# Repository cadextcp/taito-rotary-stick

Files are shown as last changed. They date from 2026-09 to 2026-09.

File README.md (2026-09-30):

# Taito Rotary Stick – druckbarer Nachbau

Nachbau des Taito „Aim-n-Fire“-Rotary-Sticks (Front Line, Wild Western, The Tin Star):
8 Rastpositionen, 4 Richtungs-Microtaster (8-Wege-Logik wie ein Joystick) und ein Fire-Taster,
der durch Herunterdrücken des Knopfs auslöst. Aufbau nach der Explosionszeichnung
„Revolving Control Assembly (WWK00003)“, Fig. 15. Parametrisch in [build123d](https://github.com/gumyr/build123d).

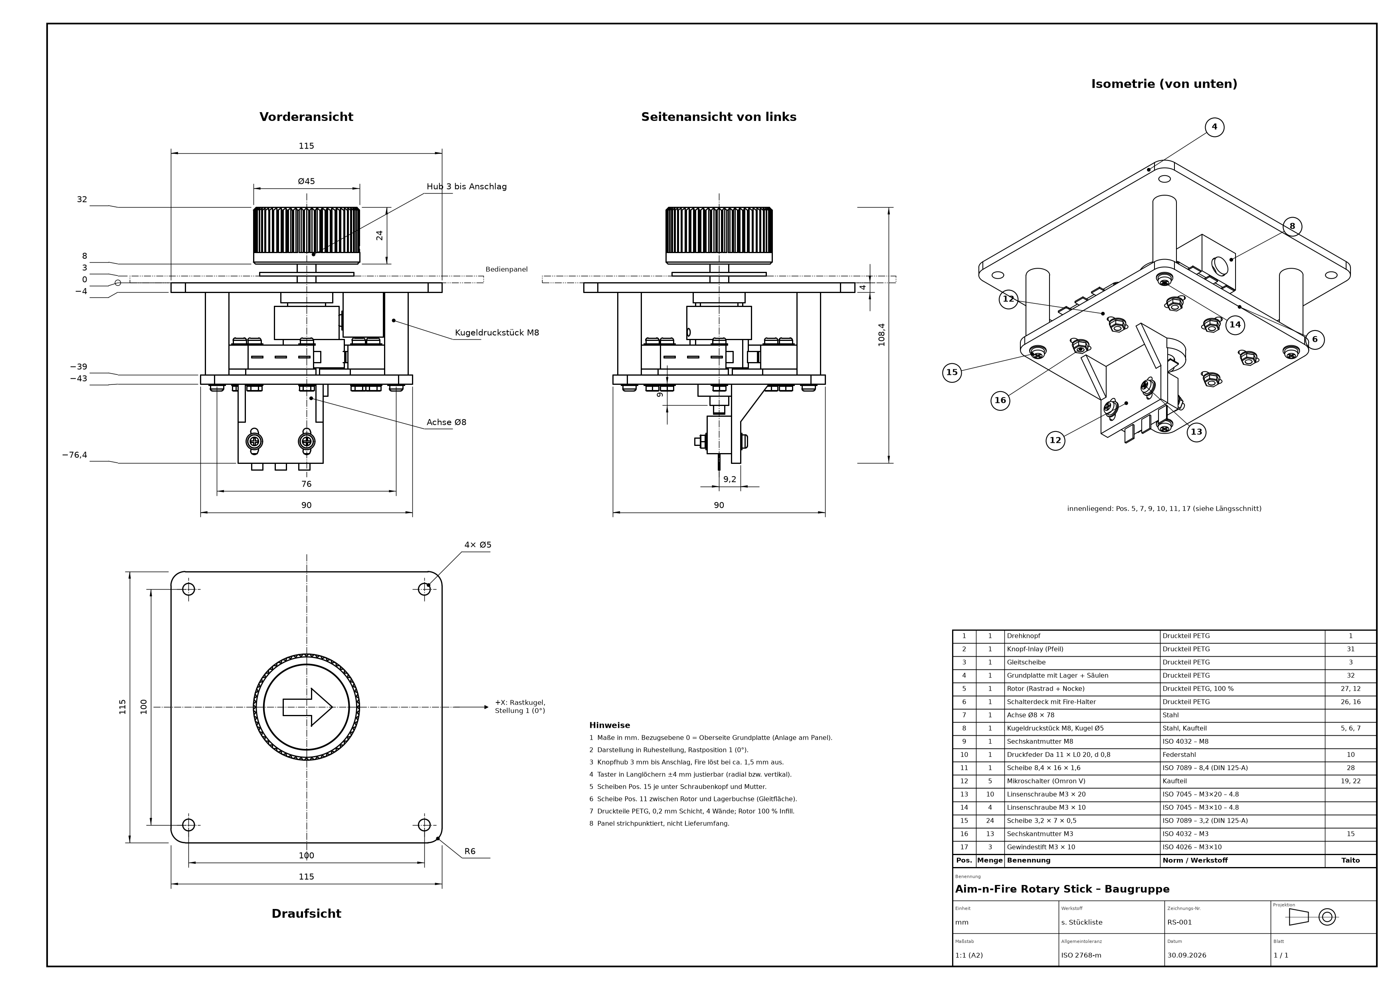
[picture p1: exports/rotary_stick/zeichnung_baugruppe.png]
Zeichnung


| Animation | Längsschnitt |
|---|---|
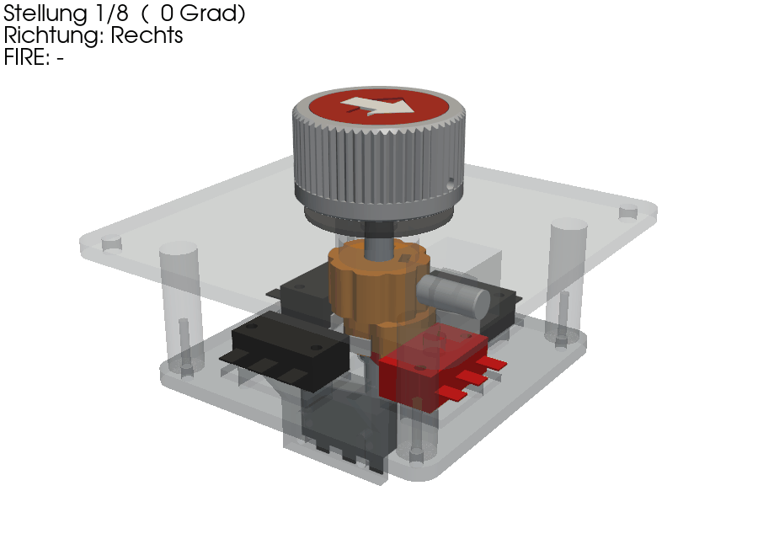
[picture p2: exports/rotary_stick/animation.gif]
Animation
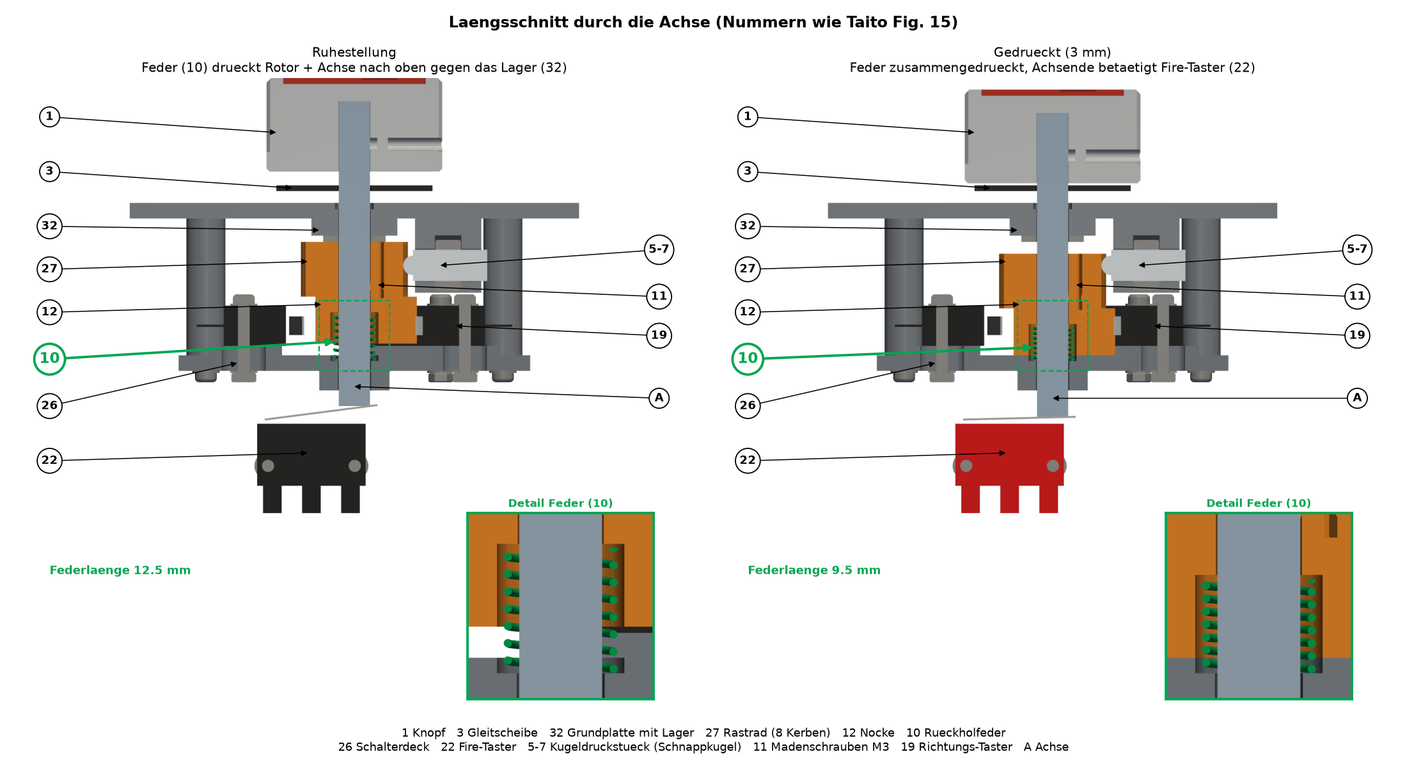
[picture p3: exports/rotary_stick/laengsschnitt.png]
Längsschnitt
|  |  |

## Inhalt

| Pfad | Inhalt |
|---|---|
| `models/rotary_stick.py` | Parametrisches Modell mit Plausibilitätsprüfungen (Schaltlogik, Kollisionen, Hub), exportiert STL/STEP |
| `scripts/drawing_rotary.py` | Bemaßte Baugruppenzeichnung A2 mit Stückliste (PDF/PNG) |
| `scripts/section_rotary.py` | Längsschnitt Ruhe/gedrückt mit Rückholfeder |
| `scripts/animate_rotary.py` | Animation Drehen/Drücken mit Tasterreaktion (GIF) |
| `scripts/render_rotary.py` | Vorschaubilder (Baugruppe, Explosion, Schaltlogik) |
| `exports/rotary_stick/` | Druckfertige STL (in Druckorientierung), STEP, Zeichnung, Bilder, [Bauanleitung](exports/rotary_stick/BAUANLEITUNG.md) |

## Funktion

- **8 Klicks:** Kugeldruckstück rastet radial in 8 senkrechte Kerben des Rastrads. Die Kerben laufen axial,
  daher stört der Fire-Hub die Rastung nicht.
- **8 Richtungen mit 4 Tastern:** Nocke mit ~96° Nockenbreite drückt in den Hauptrichtungen einen, in den
  Diagonalen zwei benachbarte Taster. Schaltfenster ≈ 3,7 mm, Taster in Langlöchern justierbar.
- **Fire:** Knopf 3 mm bis Anschlag drücken, das Achsende betätigt den unteren Taster; die Druckfeder im Rotor
  stellt zurück. Die Nocke überdeckt die Taster-Hebel über den ganzen Hub (wird im Skript geprüft).

## Neu erzeugen

```bash
python -m venv .venv
.venv/Scripts/pip install -r requirements.txt   # Linux/macOS: .venv/bin/pip
.venv/Scripts/python models/rotary_stick.py      # STL/STEP + Prüfungen
.venv/Scripts/python scripts/drawing_rotary.py   # Zeichnung
```

Maße der Kaufteile (Achse, Kugeldruckstück, Taster) stehen als Parameter oben in `models/rotary_stick.py`
und sollten vor dem Druck nachgemessen werden.

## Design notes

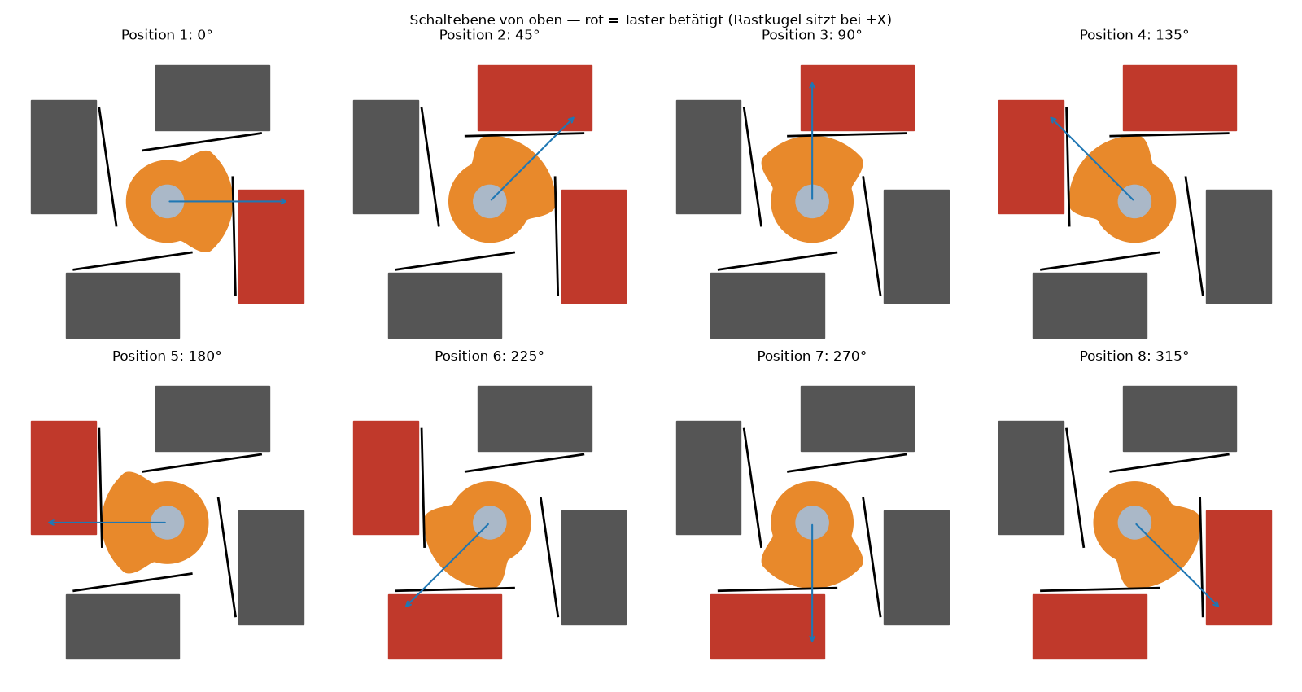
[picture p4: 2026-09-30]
exports/rotary_stick/vorschau_schaltlogik.png

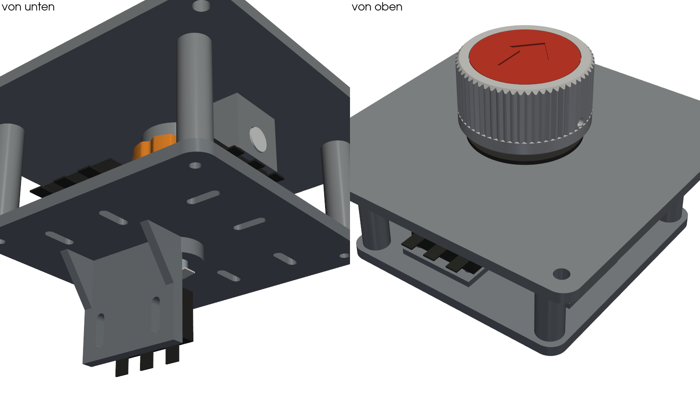
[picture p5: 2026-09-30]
exports/rotary_stick/vorschau_baugruppe.png

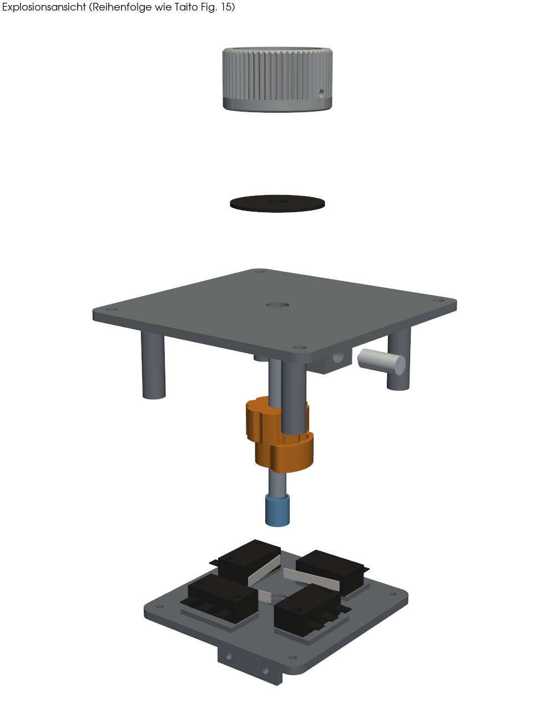
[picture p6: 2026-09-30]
exports/rotary_stick/vorschau_explosion.png

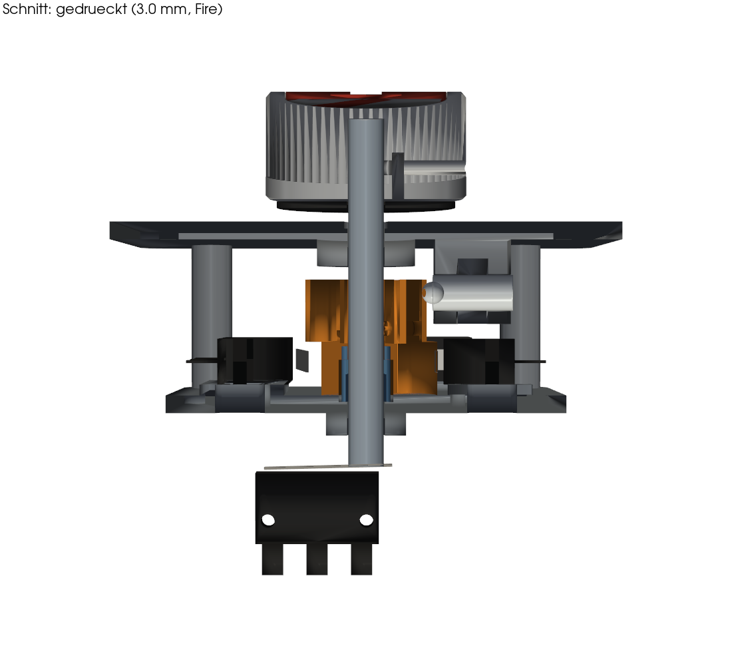
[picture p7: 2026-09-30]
exports/rotary_stick/vorschau_schnitt_gedrueckt.png

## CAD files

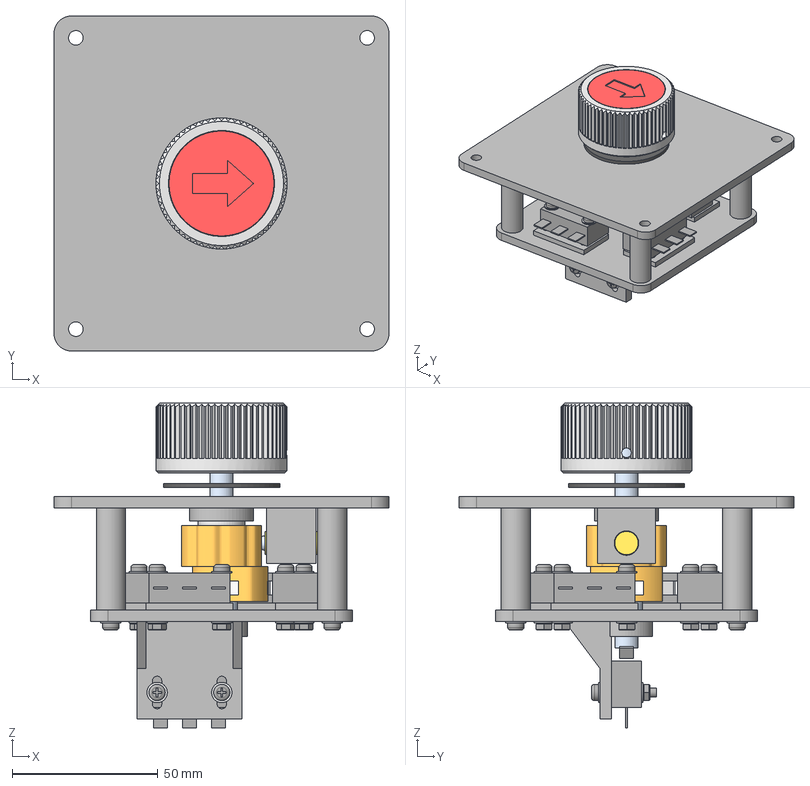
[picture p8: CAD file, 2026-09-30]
exports/rotary_stick/baugruppe.step
115.0 x 115.0 x 111.4 mm
grundplatte
rotor
schalterdeck
knopf
inlay
scheibe
achse
kugel
kugeldruckstueck
feder
taster_0
hebel_0
taster_1
hebel_1
taster_2
hebel_2
taster_3
hebel_3
taster_fire
hebel_fire
u_scheibe_28
u_scheibe_m3_o00
schraube_m3x20_00
u_scheibe_m3_u00
mutter_m3_00
u_scheibe_m3_o01
schraube_m3x20_01
u_scheibe_m3_u01
mutter_m3_01
u_scheibe_m3_o10
schraube_m3x20_10
u_scheibe_m3_u10
mutter_m3_10
u_scheibe_m3_o11
schraube_m3x20_11
u_scheibe_m3_u11
mutter_m3_11
u_scheibe_m3_o20
schraube_m3x20_20
u_scheibe_m3_u20
mutter_m3_20
u_scheibe_m3_o21
schraube_m3x20_21
u_scheibe_m3_u21
mutter_m3_21
u_scheibe_m3_o30
schraube_m3x20_30
u_scheibe_m3_u30
mutter_m3_30
u_scheibe_m3_o31
schraube_m3x20_31
u_scheibe_m3_u31
mutter_m3_31
u_scheibe_m3_d-1-1
schraube_m3x10_-1-1
u_scheibe_m3_d-11
schraube_m3x10_-11
u_scheibe_m3_d1-1
schraube_m3x10_1-1
u_scheibe_m3_d11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

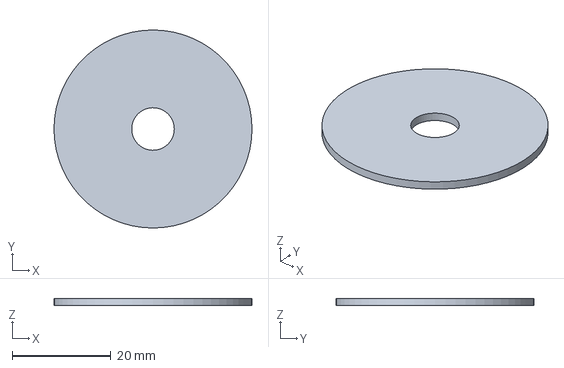
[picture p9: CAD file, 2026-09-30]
exports/rotary_stick/scheibe.step
40.0 x 40.0 x 1.50 mm

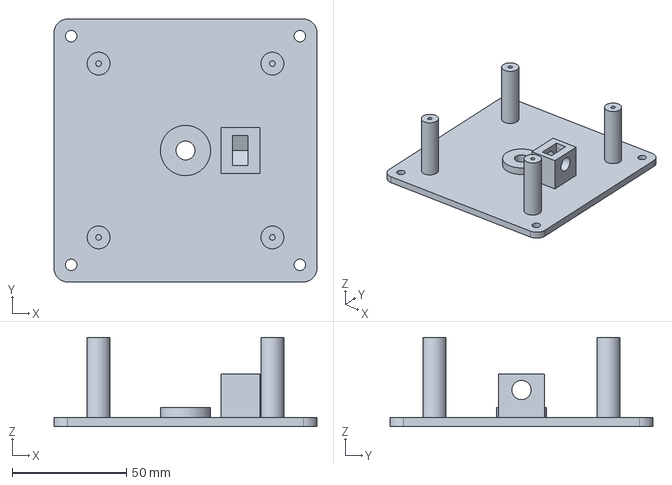
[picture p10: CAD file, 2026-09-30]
exports/rotary_stick/grundplatte.step
115.0 x 115.0 x 39.0 mm

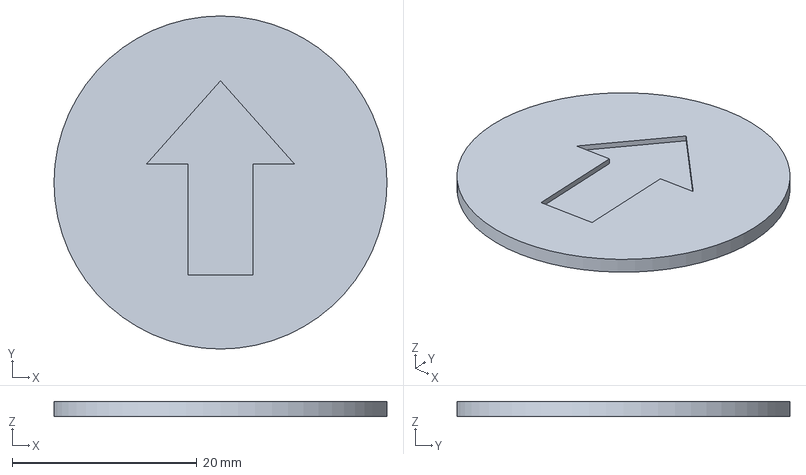
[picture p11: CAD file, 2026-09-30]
exports/rotary_stick/knopf_inlay.step
36.0 x 36.0 x 1.60 mm

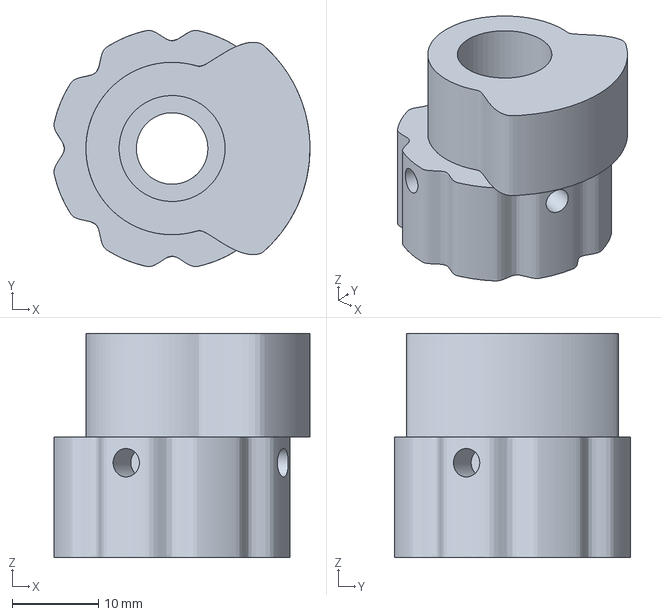
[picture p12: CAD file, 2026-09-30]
exports/rotary_stick/rotor.step
29.7 x 27.4 x 26.0 mm

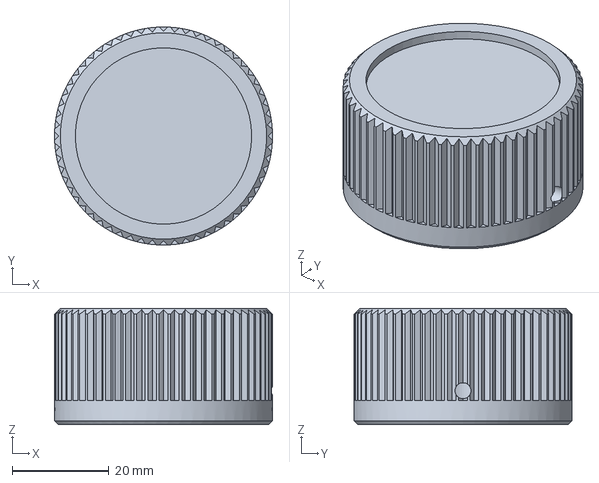
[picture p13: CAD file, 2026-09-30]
exports/rotary_stick/knopf.step
45.0 x 45.0 x 24.0 mm

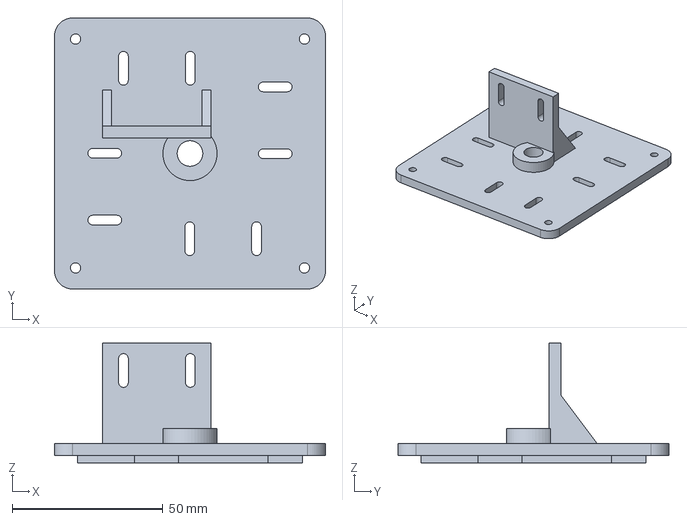
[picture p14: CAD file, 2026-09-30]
exports/rotary_stick/schalterdeck.step
90.0 x 90.0 x 39.8 mm

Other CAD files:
exports/rotary_stick/grundplatte.stl
exports/rotary_stick/knopf.stl
exports/rotary_stick/knopf_inlay.stl
exports/rotary_stick/rotor.stl
exports/rotary_stick/schalterdeck.stl
exports/rotary_stick/scheibe.stl

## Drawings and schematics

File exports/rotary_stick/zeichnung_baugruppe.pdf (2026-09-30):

# Vorderansicht

115

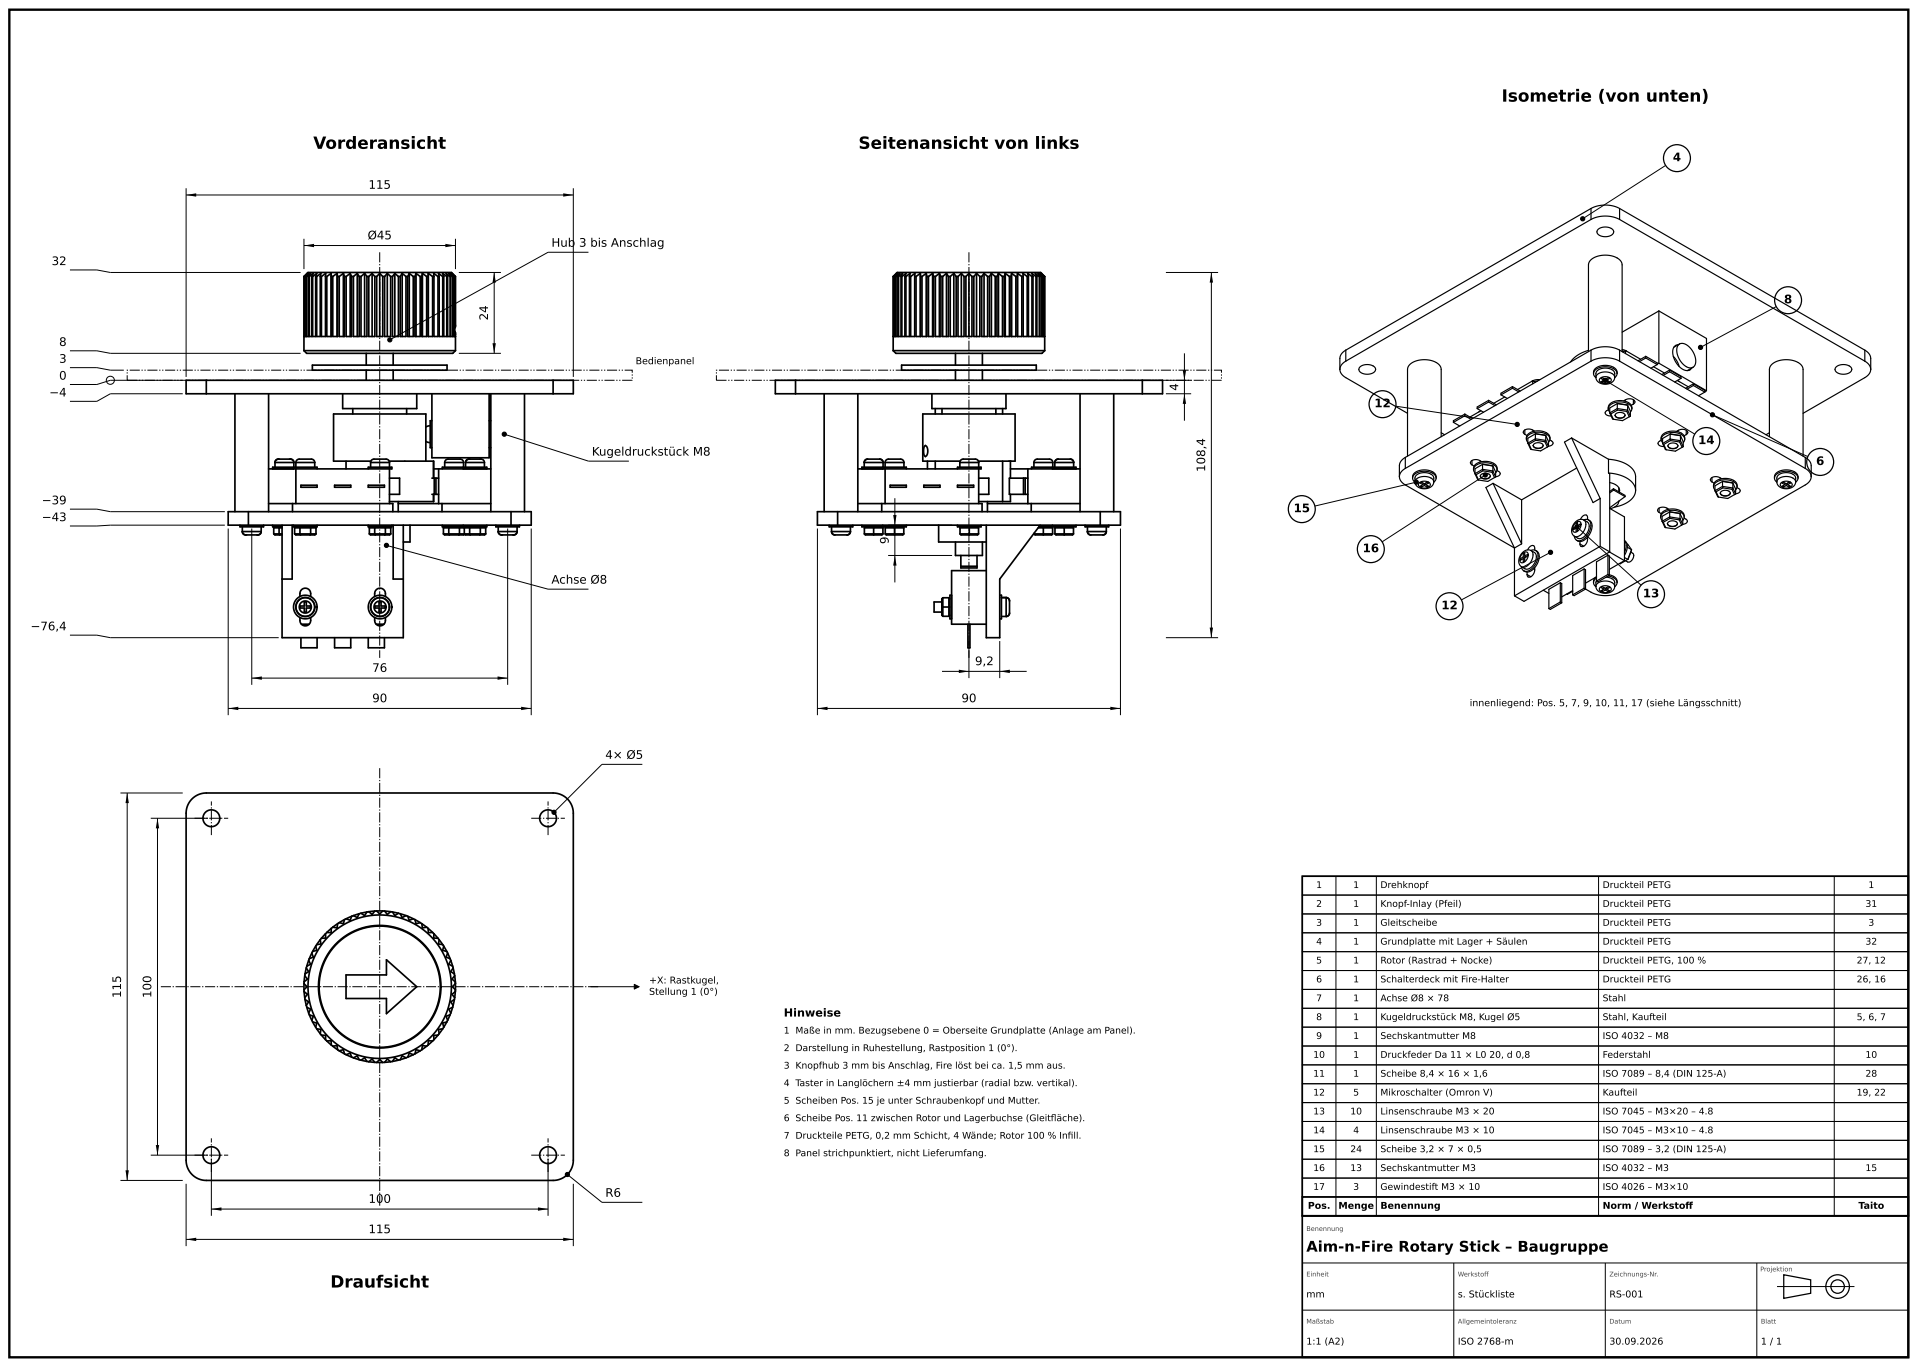
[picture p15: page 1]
Bedienpanel; Kugeldruckstück M8; Achse Ø8; Draufsicht; +X: Rastkugel, Stellung 1 (0°); Pos.; Menge; Benennung; Norm / Werkstoff; Taito; Gewindestift M3 × 10; ISO 4026 – M3×10; Sechskantmutter M3; ISO 4032 – M3; Scheibe 3,2 × 7 × 0,5; ISO 7089 – 3,2 (DIN 125-A); Linsenschraube M3 × 10; ISO 7045 – M3×10 – 4.8; Linsenschraube M3 × 20; ISO 7045 – M3×20 – 4.8; Mikroschalter (Omron V); Kaufteil; Scheibe 8,4 × 16 × 1,6; ISO 7089 – 8,4 (DIN 125-A); Druckfeder Da 11 × L0 20, d 0,8; Federstahl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

Isometrie (von unten)

Seitenansicht von links

Hub 3 bis Anschlag

innenliegend: Pos. 5, 7, 9, 10, 11, 17 (siehe Längsschnitt)

1 Maße in mm. Bezugsebene 0 = Oberseite Grundplatte (Anlage am Panel).

2 Darstellung in Ruhestellung, Rastposition 1 (0°).

3 Knopfhub 3 mm bis Anschlag, Fire löst bei ca. 1,5 mm aus.

4 Taster in Langlöchern ±4 mm justierbar (radial bzw. vertikal).

5 Scheiben Pos. 15 je unter Schraubenkopf und Mutter.
6 Scheibe Pos. 11 zwischen Rotor und Lagerbuchse (Gleitfläche).

7 Druckteile PETG, 0,2 mm Schicht, 4 Wände; Rotor 100 % Infill.

8 Panel strichpunktiert, nicht Lieferumfang.

Benennung
Aim-n-Fire Rotary Stick – Baugruppe

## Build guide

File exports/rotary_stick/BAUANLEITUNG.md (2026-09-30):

# Aim-n-Fire Rotary Stick – Nachbau

Quelle: `models/rotary_stick.py` (alle Maße parametrisch, oben im Skript).
Neu erzeugen: `python models/rotary_stick.py`, Bilder: `python scripts/render_rotary.py` (siehe README).

## Druckteile (STL liegen schon in Druckorientierung vor)

| Datei | Taito-Pos. | Hinweis |
|---|---|---|
| grundplatte.stl | 32 (+5/6/7) | Platte auf dem Bett, keine Stützen. PETG, 4 Wände, 40 % Infill |
| rotor.stl | 27 + 12 | Rastrad und Nocke in einem Teil. 100 % Infill oder 6 Wände |
| schalterdeck.stl | 26 + 16 | Oberseite auf dem Bett, Fire-Lasche wächst nach oben |
| knopf.stl | 1 | Unterseite auf dem Bett |
| knopf_inlay.stl | 31 | Pfeil ist 0,6 mm vertieft, zum Ausmalen, oder mit Farbwechsel drucken |
| scheibe.stl | 3 | Gleitscheibe zwischen Panel und Knopf |

## Kaufteile

Die vollständige Stückliste mit Positionsnummern steht auf der Zeichnung `zeichnung_baugruppe.pdf`.

- Achse Ø8 (Parameter `SHAFT_D`), Länge ≥ **78 mm** bei 3 mm Panel (+1 mm pro mm Panel)
- 5× Microtaster, Standardgröße (Omron V), 4× Richtung + 1× Fire
- 1× Kugeldruckstück M8 + 1× Mutter ISO 4032 M8 (Parameter `PLUNGER_*`, `BALL_D`)
- 1× Druckfeder, Außen-Ø ≤ 11,5, Innen-Ø ≥ 8,5, L0 ≈ 18–20 mm, weich
- 1× Scheibe ISO 7089 8,4 (8,4 × 16 × 1,6) zwischen Rotor und Lagerbuchse (Taito Pos. 28)
- 10× Linsenschraube ISO 7045 M3×20 (Taster), 4× M3×10 (Deck an Säulen, selbstschneidend)
- 24× Scheibe ISO 7089 3,2 (je unter Schraubenkopf und Mutter, dazu 4 unter den Deckschrauben)
- 13× Mutter ISO 4032 M3 (10 Taster + 3 Madenschrauben)
- 3× Gewindestift ISO 4026 M3×10 (2× Rotor, 1× Knopf)

## Montage

1. M8-Mutter von unten in den Schlitz des Halteblocks schieben, Kugeldruckstück von außen eindrehen, aber noch nicht bis an den Rotor.
2. Achse von oben durch die Grundplatte stecken, zuerst die Scheibe 8,4, dann den Rotor (Rastrad oben) aufschieben. Rastkerbe 0° zeigt zum Kugeldruckstück. Rotor an die Lagerbuchse schieben, Madenschrauben anziehen.
3. Feder in die Tasche unten im Rotor stecken, Schalterdeck aufsetzen und an die 4 Säulen schrauben.
4. 4 Taster flach auf die Sockel des Decks legen (Schraube von oben mit Scheibe, unten Scheibe + Mutter), **Hebelspitze zur Nocke hin** (siehe `vorschau_schaltlogik.png`). In den Langlöchern so justieren, dass jeder Taster auf dem Nocken klickt, auf dem Grundkreis aber nicht (Schaltfenster ≈ 3,7 mm).
5. Fire-Taster an die Lasche schrauben, Hebel unter das Achsende. Höhe so einstellen, dass er nach ca. 1,5 mm Druckweg auslöst (Anschlag bei 3 mm).
6. Kugeldruckstück eindrehen, bis die Klicks sauber sind, dann mit mittelfester Schraubensicherung sichern.
7. Scheibe und Knopf aufsetzen, Pfeil zur gewünschten Richtung ausrichten, Madenschraube anziehen.

## Schaltlogik (Taster 0 = Kugelseite +X, dann 90° gegen den Uhrzeigersinn)

| Stellung | 0° | 45° | 90° | 135° | 180° | 225° | 270° | 315° |
|---|---|---|---|---|---|---|---|---|
| Taster | 0 | 0+1 | 1 | 1+2 | 2 | 2+3 | 3 | 3+0 |

Die Stellungen verhalten sich wie ein 8-Wege-Joystick. Die Taster lassen sich direkt als Hoch/Rechts/Runter/Links an ein Encoder-Board anschließen.

## Vor dem Druck prüfen

- Achs-Ø und -länge
- Gewinde und Kugel-Ø des Kugeldruckstücks
- Lochabstand der Taster: Parameter `SW_HOLE_FROM_BOTTOM` (5,1 mm) nachmessen
- Befestigungslöcher für das Panel: `PLATE_HOLE_POS`
